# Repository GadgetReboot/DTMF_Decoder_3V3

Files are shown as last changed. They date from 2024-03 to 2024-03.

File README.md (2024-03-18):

# DTMF_Decoder_3V3
MT88L70 based DTMF decoder with 3.3v power/logic
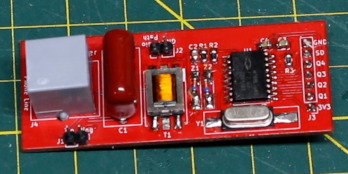
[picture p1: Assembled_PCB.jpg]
PCB
<br><br><BR><BR>
This DTMF decoder uses the MT88L70, powered by 3.3v and interfacing with 3.3v GPIO to decode the touch tone keys.<BR>
It has an RJ phone jack and 600:600 transformer to connect to a phone line to pick up audio, listening for DTMF tone pairs.<BR><BR>
Note: It is recommended to only connect this circuit to a phone line after it is taken off hook to keep the AC voltages low, such as audio signals and not a high voltage ring signal.
This can be achieved by switching the circuit into the phone line with a relay.

This circuit has only been tested on a simulated phone line in a workshop environment and is not guaranteed to meet official telephone line specifications.

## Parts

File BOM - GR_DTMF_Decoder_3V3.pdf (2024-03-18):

DTMF Decoder 3V3 BOM

Item # | Reference Designator | Qty | Manufacturer | Mfg Part # | Description / Value | Package/Footprint | Type | Instructions / Notes
1 | C2 C3 C4 | 3 | Samsung | CL21B104KBCNNWC | CAP CER 0.1UF 50V X7R 0805 | 0805 | SMD
2 | C1 | 1 | Panasonic | ECW-F2105HA | Film Capacitor 1.0uF 250VDC 3% MPP L/S=15mm | Radial | THRU-HOLE
3 | J1 J2 | 2 | Sullins | PREC002SAAN-RC | Connector Header Through Hole 2 position 0.1" | 2POS | THRU-HOLE
4 | J3 | 1 | Sullins | PREC007SAAN-RC | Connector Header Through Hole 7 position 0.1" | 7POS | THRU-HOLE
5 | J4 | 1 | Ckmtw(Shenzhen Cankemeng) | R-RJ11R06P-A800 | RJ11 RJ Receptacle Modular Connector | 6POS | THRU-HOLE
6 | R4 R5 | 2 | Panasonic | ERJ-6GEYJ103V | RES SMD 10K OHM 5% 1/8W 0805 | 0805 | SMD
7 | R1 R2 | 2 | Panasonic | ERJ-6GEYJ104V | RES SMD 100K OHM 5% 1/8W 0805 | 0805 | SMD
8 | R3 | 1 | Panasonic | ERJ-6GEYJ304V | RES SMD 300K OHM 5% 1/8W 0805 | 0805 | SMD
9 | T1 | 1 | Bourns | SM-LP-5001E | Audio Transformer 600uH 7.36mm SMT Line Matching | SMT-6 | SMD
10 | U1 | 1 | Microchip Technology | MT88L70AS1 | Telecom Interface 3 Volt DTMF Reveiver | SOIC-18 | SMD
11 | Y1 | 1 | ABRACON | ABLS2-3.579545MHZ-D4Y-T | CRYSTAL 3.579545MHZ 18PF SMD | HC-49/US | SMD
12 | Z1 Z2 | 2 | Vishay Semiconductors | TZMC2V4-GS08 | Zener Diodes 2.4 Volt 0.5 Watt 5% | SOD-80 | SMD

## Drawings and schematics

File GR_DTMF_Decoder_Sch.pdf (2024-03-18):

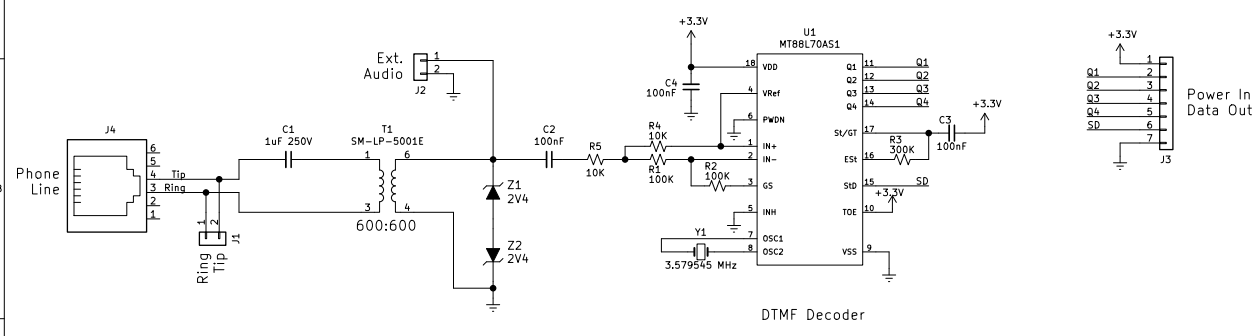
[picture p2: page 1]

https://github.com/GadgetReboot/DTMF_Decoder_3V3
https://www.youtube.com/gadgetreboot
File: GR_DTMF_Decoder.sch Sheet: / Gadget Reboot

Id: 1/1 Title: DTMF Decoder 3.3V

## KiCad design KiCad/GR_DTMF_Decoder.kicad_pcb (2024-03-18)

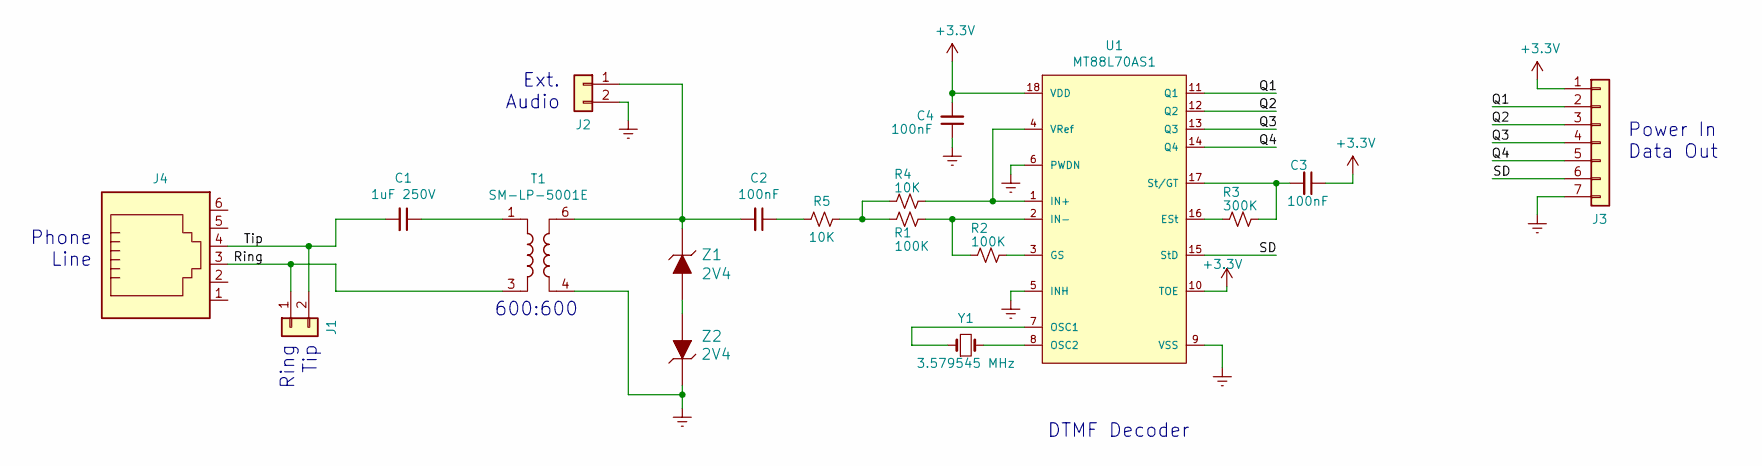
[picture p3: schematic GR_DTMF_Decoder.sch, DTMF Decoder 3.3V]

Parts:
C1: 1uF 250V; C_Rect_L18.0mm_W8.0mm_P15.00mm_FKS3_FKP3
C2, C3, C4: 100nF; C_0805_2012Metric_Pad1.15x1.40mm_HandSolder
J1, J2: Conn_01x02; PinHeader_1x02_P2.54mm_Vertical
J3: Conn_01x07; PinHeader_1x07_P2.54mm_Vertical
J4: RJ12; RJ_6p6c
R1, R2: 100K; R_0805_2012Metric_Pad1.15x1.40mm_HandSolder
R3: 300K; R_0805_2012Metric_Pad1.15x1.40mm_HandSolder
R4, R5: 10K; R_0805_2012Metric_Pad1.15x1.40mm_HandSolder
T1: SM-LP-5001E; Transformer_SMLP5001
U1: MT88L70AS1; SOIC-18W_7.5x11.6mm_P1.27mm
Y1: 3.579545 MHz; Crystal_SMD_HC49-SD_HandSoldering
Z1, Z2: 2V4; Zener_MiniMELF; MPN ZMM3.3; Digi-Key_PN Diotec Semiconductor

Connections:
+3V3: C3.1, C4.2, J3.1, U1.10 (TOE), U1.18 (VDD)
/Q1: J3.2, U1.11 (Q1)
/Q2: J3.3, U1.12 (Q2)
/Q3: J3.4, U1.13 (Q3)
/Q4: J3.5, U1.14 (Q4)
/Ring: J1.1, J4.3, T1.3
/SD: J3.6, U1.15 (StD)
/Tip: C1.2, J1.2, J4.4
GNDREF: C4.1, J2.2, J3.7, T1.4, U1.5 (INH), U1.6 (PWDN), U1.9 (VSS), Z2.K
unnamed: C1.1, T1.1
unnamed: C2.1, R5.2
unnamed: C2.2, J2.1, T1.6, Z1.K
unnamed: C3.2, R3.1, U1.17 (St/GT)
unnamed: R1.1, R2.2, U1.2 (IN-)
unnamed: R1.2, R4.1, R5.1
unnamed: R2.1, U1.3 (GS)
unnamed: R3.2, U1.16 (ESt)
unnamed: R4.2, U1.1 (IN+), U1.4 (VRef)
unnamed: U1.7 (OSC1), Y1.1
unnamed: U1.8 (OSC2), Y1.2
unnamed: Z1.A, Z2.A

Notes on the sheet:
DTMF Decoder
Power In Data Out
Phone Line
Ext. Audio
600:600
Ring
Tip

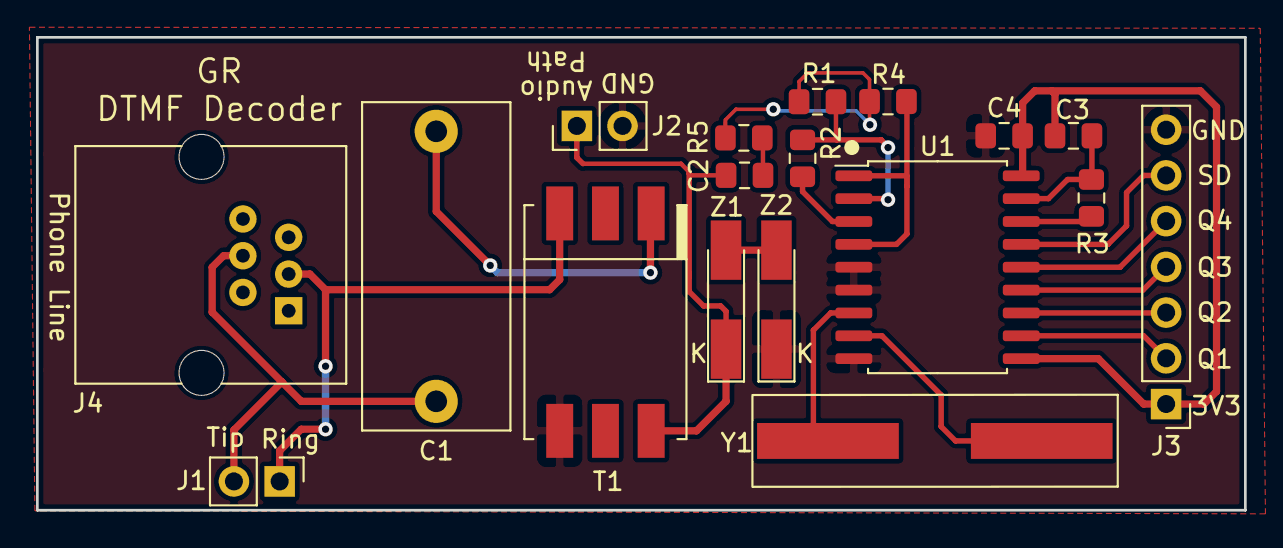
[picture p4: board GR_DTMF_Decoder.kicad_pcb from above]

Board: 2 copper layers, 67.1 x 26.3 mm, 18 parts (0 on the bottom side), 21 nets.
